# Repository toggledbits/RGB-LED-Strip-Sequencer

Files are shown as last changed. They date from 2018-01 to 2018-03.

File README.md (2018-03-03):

# RGB LED Strip Sequencer using Arduino & Adafruit Trellis #

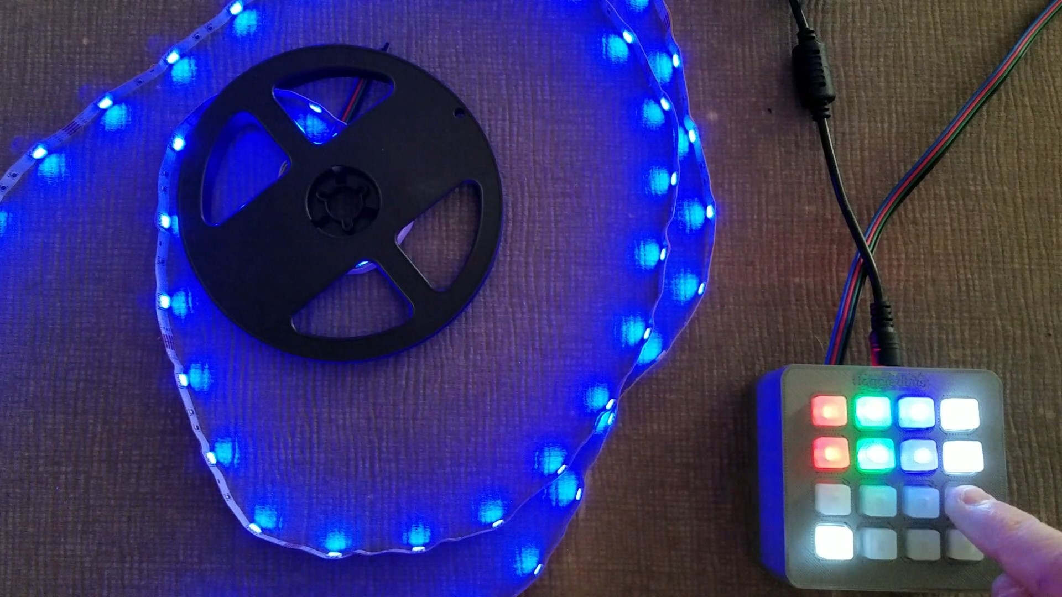
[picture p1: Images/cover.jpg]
toggledbits RGB LED Strip Sequencer (Arduino and Adafruit Trellis)


## Background ##

My wife had been asking me to install LED strips on my boys' hutch-style desks, which were a little dark.
The boys told me they wanted cool color LEDs, not just the white strips that their Mom and I use.
I bought a couple of RGB LED strips on Amazon, most of which seem to come as kits with a power supply 
and controller. But having used the included controllers before, I know that their canned patterns
would quickly become boring to my boys. So, I thought it would better if I built something, using an
Arduino Nano or something similar.

As I thought about the project a little more, I realized that it could be a great opportunity to give them
an intro to programming live projects with a useful result. I've been teaching them programming for a few
months now, but we've mostly been printing to a shell stdout or web page. Here, I had an opportunity to let
them program to blink lights! Any way they want!

So, the project quickly morphed from a 30-minute job getting LED strips to stick to the desk frame to several
weeks of tinkering with Arduino Sketch, circuit design, board layout, and 3D printing. My concept was to build
an Arduino-based LED sequencer that they could use to create simple patterns from a user interface of some kind,
or as their skills grew, implement their patterns within a Sketch that acted like a framework: they just supply
their one part at first, but later they can venture into any part of the code they want.

This repository contains what is currently my version 1.1 effort. 

## What It Does ##

[See it in action on YouTube!](https://youtu.be/xU6wqpSIGhU)

The Arduino drives three MOSFETs to drive the color channels of the LED strip. An [Adafruit Trellis](https://www.adafruit.com/product/1616) 4x4 button 
matrix is used to create the user interface. Color-keying of the button LEDs helps provide visual cues to function
(e.g. changing the red channel intensity is done using the red buttons, green channel using green buttons, etc.).

To turn the project on, long-press the lower-left button. The project lights up all LEDs, then turns off the
bottom two rows except the lower-left (power) button.

The two top rows of buttons change the color intensity of the red, green, and blue channels. Pressing the white
buttons changes the LED strip color to white (all channels driven equally) and varies the intensity in the same
manner as the individual color buttons.

Eight preset patterns are stored in the Arduino's EEPROM. A pattern can be played by pressing one of the eight
buttons in the lower two rows of the pad. The button blinks while the pattern is running. Pressing the button
again stops the pattern. Pressing a different pattern button starts that new pattern. Pressing the intensity
buttons (top two rows) stops the pattern at its current step and changes the color accordingly.

The EEPROM-based patterns can be edited using the keypad interface. A long-press (more than one second) on a
pattern button puts the project into editing mode for that pattern. When in editing mode, the upper two rows
of buttons blink, and the LED strip shows the color of the current step. Pressing the intensity buttons modifies
the color for that step. When a satisfactory color is set, a short press on the pattern button advances to the next step.
These steps are continued until editing completes, either by short press on the 16th step (max 16 steps per pattern), 
or by long-pressing the pattern button at any point. The modified pattern then automatically runs.

To turn the project off, long-press the lower left button.

A "factory reset" of the project, restoring the original default patterns to EEPROM, can be done by pressing
and holding the bottom left and bottom right buttons until the top two LEDs light. Release the buttons, and the
project will restore defaults to EEPROM.

## Operation and Development ##

### Driving the LED Strip ###

The first thing I did was wire up a proto board using MOSFETs to drive the color channels. I used IRLB8721s because
I had a bunch around and they would be fine for handling fairly hefty wattages. The MOSFETs are driven
by the PWM-capable digital outputs on the Ardunio (D9-11, specifically), allowing brightness control.

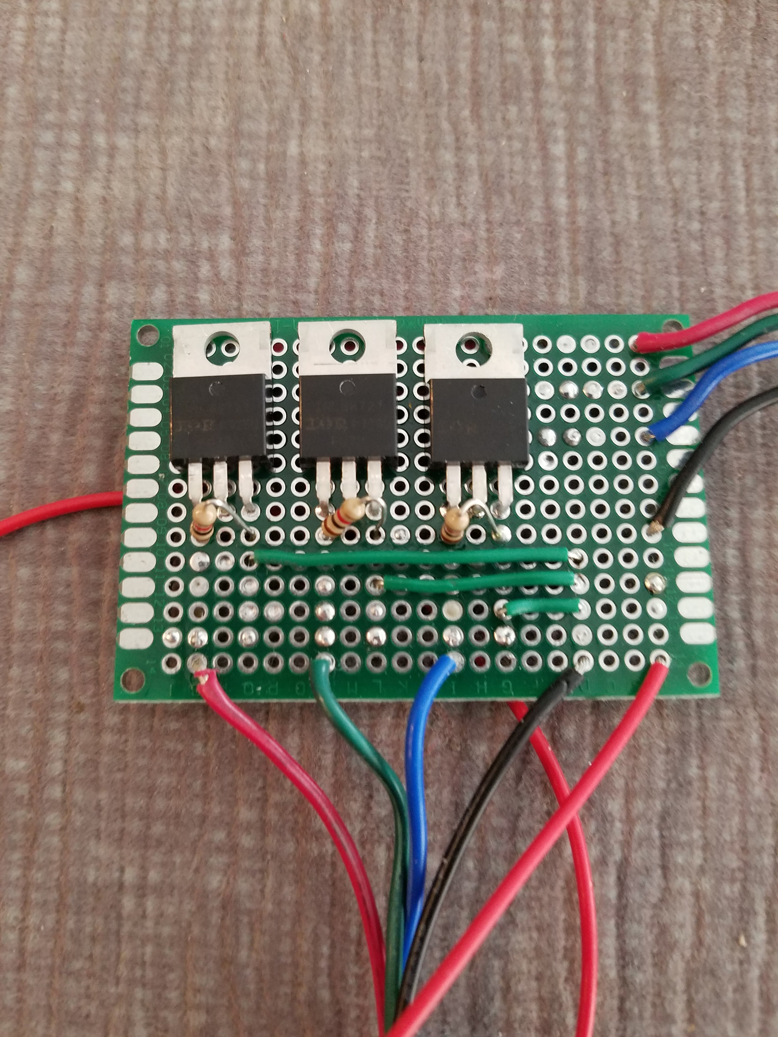
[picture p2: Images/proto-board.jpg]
toggledbits The proto board


### Discovering a User Interface ###

For an interface, I had often used the uniquitous 16x2 LCD with four or five tactile switches for projects, 
but I felt that that kind of interface was going to be slow and clumsy for this purpose. 
What I really thought would work well was a 
matrix of lighted buttons like they use on MIDI controllers. I thought it would be easy to create a simple but
powerful (enough) user interface on it, and the boys would think it was really cool-looking (shout out to Thomas Dolby for
that--it's a long story, maybe ask me over a beer). So I started researching how to build one. Hmmm. That was going
to get expensive. OK, is there an off-the-shelf product that didn't look like a DTMF or calculator keypad
that I could interface with? Few, all expensive.

I don't recall how I found it, but I ended up stumbling across the Adafruit Trellis. It's (as of this writing)
a $9.95 board (plus $4.95 for the silicone keypad--not sure why they sell it separately) with a 4x4 matrix of
addressable switches. The board doesn't come with LEDs, but you can provide your own and solder them to pads
provided. The Arduino library lets you check button states and turn LEDs on and off with simple function calls, and 
the board uses two-wire (I2C) communication. You can even connect up to eight together to make larger matrices.

I ordered one, and started playing with it as soon as it arrived. Perfect. I soon had it working on the Arduino,
and from there, imagining an interface and getting it to work took only a couple of hours.

With the user interface shaping up, I connected everything together, supplied power to the LED strip, and played
with my new toy. This was going to work great for the boys.
Except, I could not imagine putting a spaghetti bundle of three boards and wiring on their desks. That was
fraught with peril. I needed an enclosure, but that wasn't going to be enough.
The solder-globbing style of proto board work left me feeling like it was going to be
a permanently unpolished project. The case my hide the worst of it, but I wanted the project to
look as polished on the inside as it was on outside. The driver board had to be cleaned up.

### Version 1.0 is Born ###

I started designing the driver board as a proper printed circuit board (PCB). It seemed obvious to me to make it a
shield for the Arduino, so the connections between the two could be many and firm. After Googling out a few diagrams,
I had a board properly dimensioned with headers in the right places to be a shield. A quick print at actual size
confirmed the fit. Adding the driver circuit to the board from there was easy, as my driver circuit is simple and even the
small size of the Arduino footprint left plenty of room.

The next consideration was simplifying the power supplies. In the prototype, the LEDs were separately powered, and the
Arduino drew its power from the USB port. It had to work standalone from a single supply. I double-checked the specs for 
the Uno, and 12V supply wasn't going to be a problem. Checking the schematic, I could see there was a VIN header pin that would
give me the supply voltage, but there was a potential problem: the PJ202 jack on the Arduino has a protection diode connected between it and that VIN pin, 
and that diode (and probably the traces on the Arduino) were unlikely to handle the potential power demand that the LED strip
would make on them. The schematic quickly confirmed, however, that I could supply power *to* the Arduino on
the VIN pin, and have the 12V supply connect directly to the shield. This left the matter of getting a 5V supply to the
Trellis, but that's easy because the Arduino supplies 5V from its on-board regulated supply on a header pin. So, in the final result,
12V is supplied to the shield, which sends 12V to the Arduino over VIN, which sends 5V back to the shield, which sends that 5V up to
the Trellis. And, the shield traces are all large enough to handle the larger currents the LED strips require. Done.

Right before I sent the boards out to be fabricated, I realized that I could make holes for stand-offs, so the Trellis could
mount to the shield. This would make a sandwich: Arduino on the bottom, shield connected to it, and Trellis connected to shield
on top. Perfect. I just had to move two traces slightly to get the Trellis mounting holes where they needed to be, and off the v1.0 
board went to the board house.

When I got the boards back, everything went together perfectly. I tested the board standalone, driving it with my bench
power supply, and it seemed to work fine. When I hooked it up to the Arduino, everything worked perfectly. So there it was,
version 1.0.

Check out the [YouTube video](https://youtu.be/SFQtTEeX06Y).

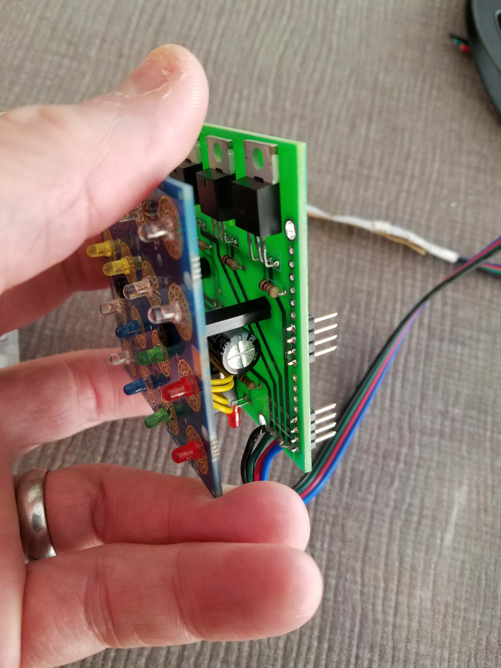
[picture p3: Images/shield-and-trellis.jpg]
toggledbits Trellis on Shield


It took me a few attempts to get the 3D-printed enclosure dialed in. I've only recently started using Fusion 360, and I find it
quite intuitive and easy to work in. I really love it. It's much easier to use and more powerful than my previous go-to tool,
123D Design (also AutoDesk, now discontinued). The lid was actually a snap, because the holes for the Trellis' buttons
are very precisely spaced and Fusion 360 has tools for exactly
that kind of thing. It took me less than 30 minutes to design a lid, and that design changed very little throughout. The body,
however, had holes in two of its vertical sides, and getting those positioned so that they ended up lining up right with my three-board
sandwich took a couple of attempts. Each test print of the body took about 4 hours to print with 200u layers, so it wasn't that it was hard, 
it just took time (shout out to [Josef Prusa and crew](https://www.prusa3d.com/) here--this was my first time using 
my new Prusa i3 MK2S Christmas present on a real project, and it performed beautifully).

The final design looks clean and fits OK. The Arduino is inserted first, on its own, into the bottom of the body. The
shield with the Trellis mounted is then inserted into the Arduino. The lid is then pressed on over the Trellis, and is
held by friction. I could tweak it to death, but I have other ideas about how I want to modify the project that will require
big changes to the enclosure, so it's not worth my time at the moment to sweat over a millimeter here or there.

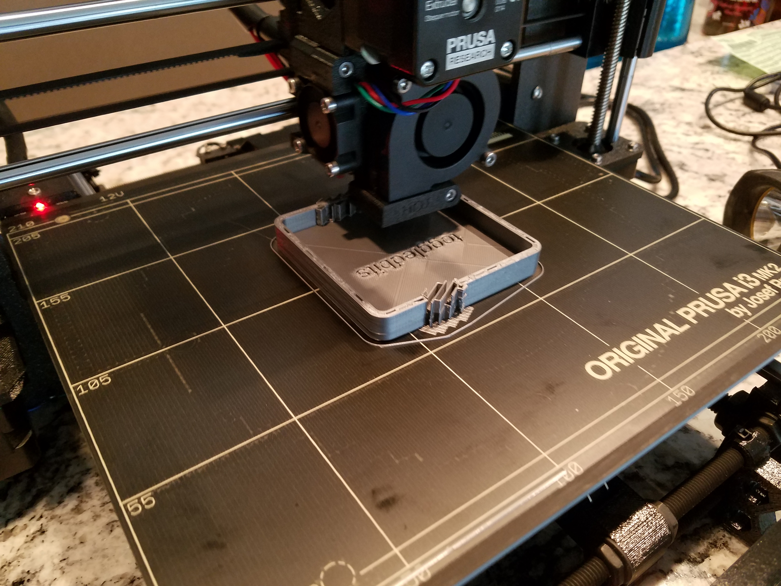
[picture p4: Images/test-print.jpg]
toggledbits An early test print


### Today: Version 1.1 ###

As happens with all prototypes, you discover a few mistakes along the way. In the process of building the first unit for
my older boy, and writing the Instructable to describe the process, I realized that I made two mistakes I would need to
correct right away:

* I needed a protection diode to prevent any power directly into the Arduino from trying to power the LEDs. That is, if
the project was connected to USB for Sketch updating and the 12V supply was not connected, the Arduino would be sending
USB power at 5V up to the shield on the VIN pin, and the shield would attempt to power the LEDs with it. To prevent that,
a diode facing the Arduino has been added to the shield, which blocks any backfeeding of the shield from the Arduino. The
Arduino can be safely connected to USB, and will even power the Trellis, but it won't power the LED circuit on the shield.
* I had forgotten to current limit the digital pins--whoops!--so I added R5-7.
* I had not yet provided a way in the Sketch code to control the rate at which patterns are run. This is now done. In the
run mode, the white up/down keys control the pattern rate. The pattern is stored in EEPROM with the pattern.

So, as it stands today, the project consists of:

1. The custom-designed Arduino shield that creates all of the interfaces for the circuit: input, output, and power;
1. The Arduino Sketch that drives the shield and the Adafruit Trellis;
1. The enclosure designed in Fusion 360 to fit the current hardware configuration.

## What's Next ##

My current thoughts about the next revision of this project are:

1. A version of the driver that accepts a Nano or Feather directly. This will "shorten" the sandwich and make a more compact design.
1. WiFi-enable it so my home automation system can monitor and control it.
1. Modify the case design to that the boards are inserted from the bottom. This will make fitting them into the case easier.
1. I can see how some of the subtle design choices for the enclosure (like wall thickness) dramatically affect print time, so I'll tune the enclosure to make printing quicker and use less material.

## Build One! ##

If you want to build one, check out the [YouTube video](https://youtu.be/SFQtTEeX06Y) and [Instructable](https://www.instructables.com/id/Programmable-RGB-LED-Sequencer-using-Arduino-and-A/) I made about building this project.

This Github repository contains all of the files you need: schematics, board layouts (if you decide to build the shield instead of just
using a proto board or breadboard), the Arduino Sketch, and the enclosure model (STL) files.

The enclosure models (STLs) are also [on Thingiverse](https://www.thingiverse.com/thing:2768560).

## Write Your Own Pattern Runner ##

As of version 1.1 of the code, you have the ability to easily write your own patterns into Sketch, if the pushbutton
user interface doesn't provide you enough flexibility. Here's what you need to know.

Patterns are run by a subclass of `PatternRunner`. Your class must have three methods: `start`, `next`, and `stop`. You
can look at the class `ColorWheelRunner` as an example. The `start` method is used to do whatever is necessary to 
initialize the pattern. It must also set the LED strip to the pattern's first step (see below). The `next` method is
then called repeatedly at the pattern delay interval to put the next pattern on the LED strip. Your subclass must
maintain enough state (e.g. private data) to know what step is next. Finally, when the user wants to stop the pattern,
the `stop` method is called. In most cases, this method really won't need to do anything.

To set the LED strip colors, the subclass methods should set the `red`, `green`, and `blue` global variables to the
desired values (0-255), and then call `setRGBW()`. Yes, the globals are gross and the OO is inconsistent; I'll clean
it up some day, I promise.

To set the default pattern delay interval, your subclass can set the global `nextStepDelay`. This value is in milliseconds,
and must be greater than or equal to zero.

To bind your runner to a button, go to the `setup()` function, and near its end you'll see the code below. The bold line is an example
of how and where you add your pattern runner. In this example, we bind a new runner to pattern 0 (first button the third row).

<pre>
  EEPROMRunner er = EEPROMRunner();
  for ( uint8_t i=0; i<8; ++i) {
    patternRunners[i] = &er;
  }
  /* Provide any overrides for the default pattern function here */
  patternRunners[4] = new ColorWheelRunner(); /* override for button 13/power button/pattern 5 */
  <b>patternRunners[0] = new MyNewPatternRunner();</b>
</pre>

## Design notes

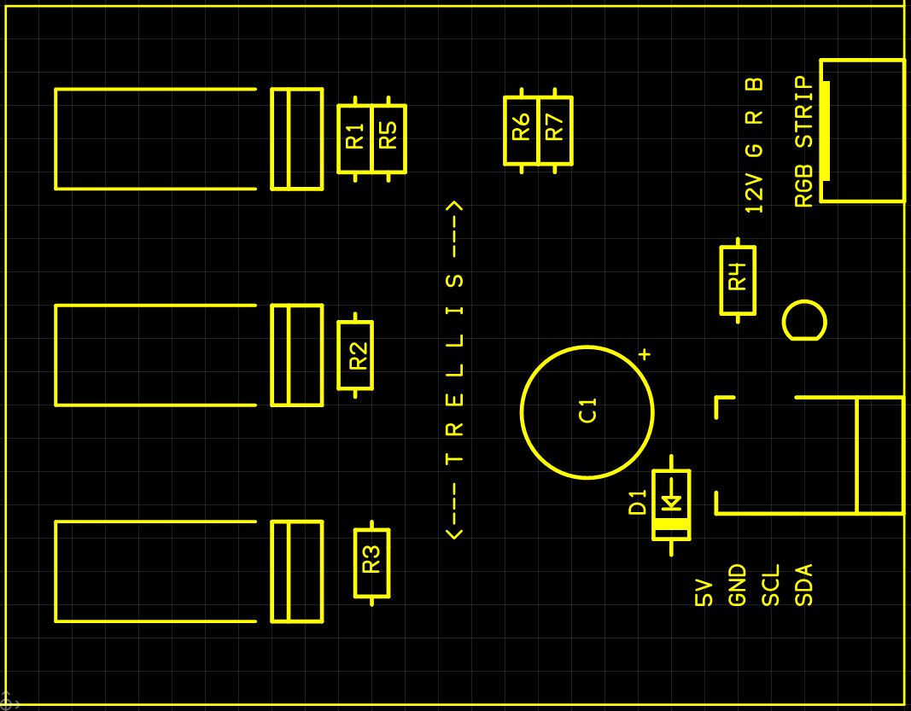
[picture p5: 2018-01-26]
Shield/RGB LED Driver Shield-v1.1-silk.PNG

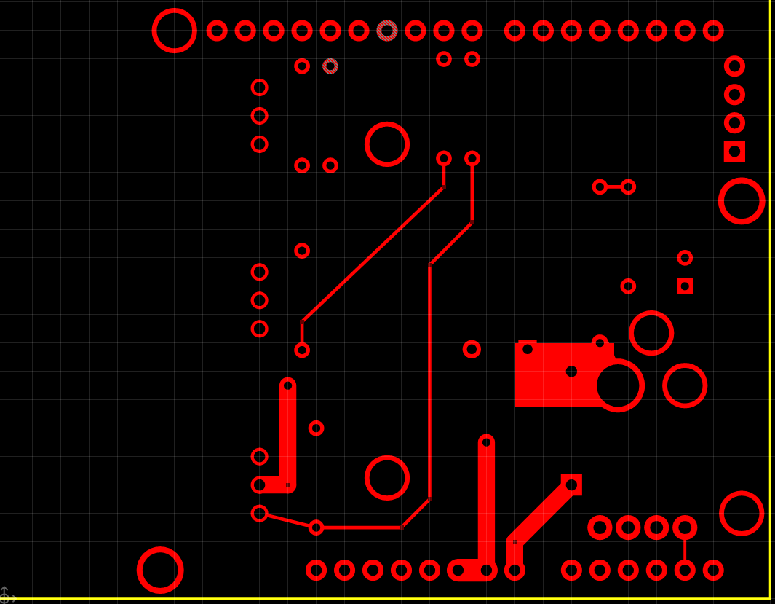
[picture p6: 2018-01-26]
Shield/RGB LED Driver Shield-v1.1-top.PNG

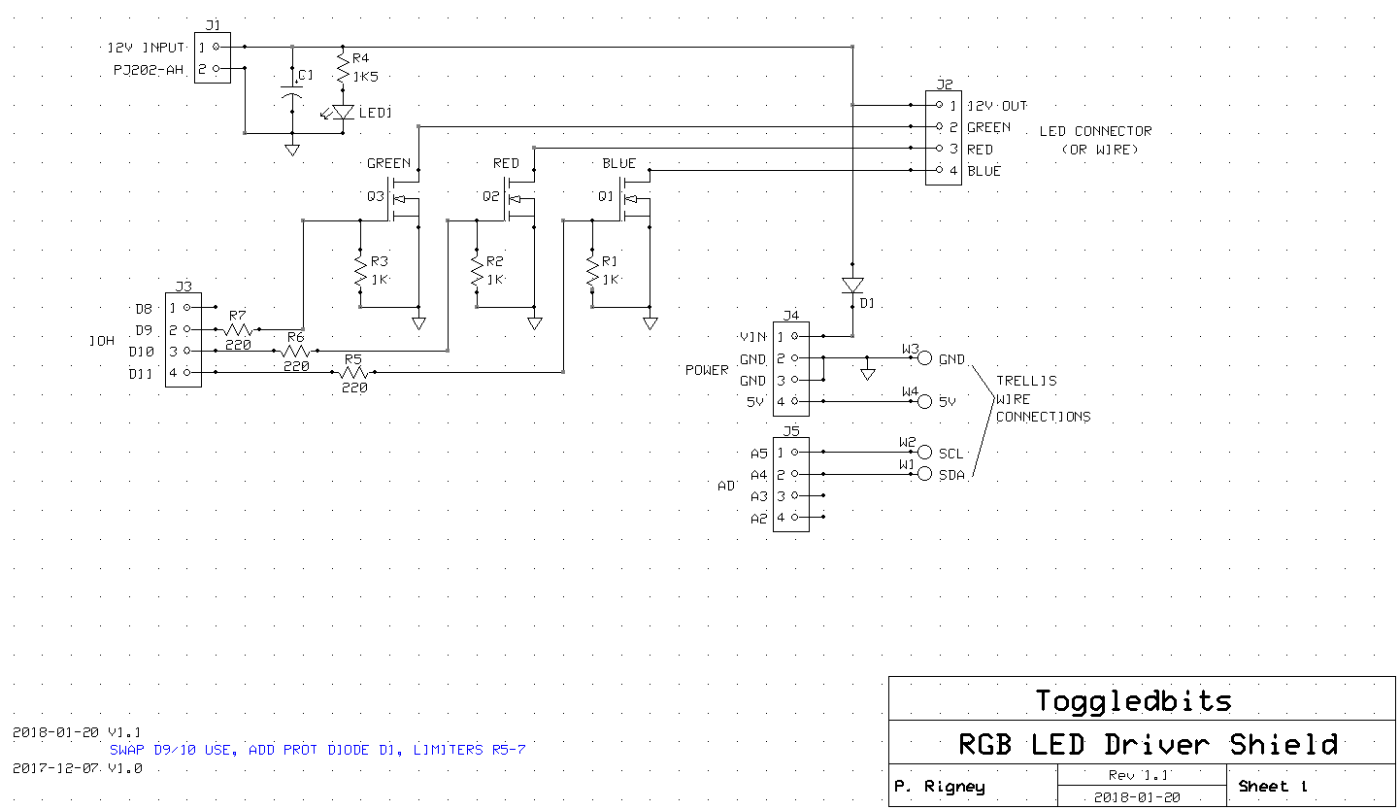
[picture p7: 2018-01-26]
Shield/RGB LED Driver Shield-v1.1-schem.PNG

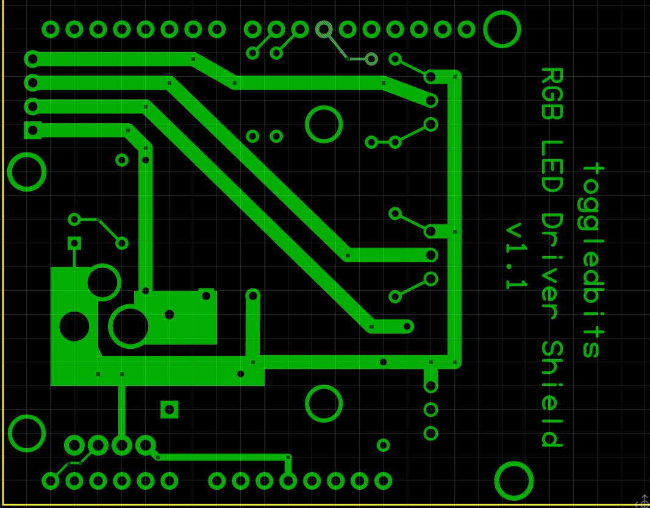
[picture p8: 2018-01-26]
Shield/RGB LED Driver Shield-v1.1-bottom.PNG

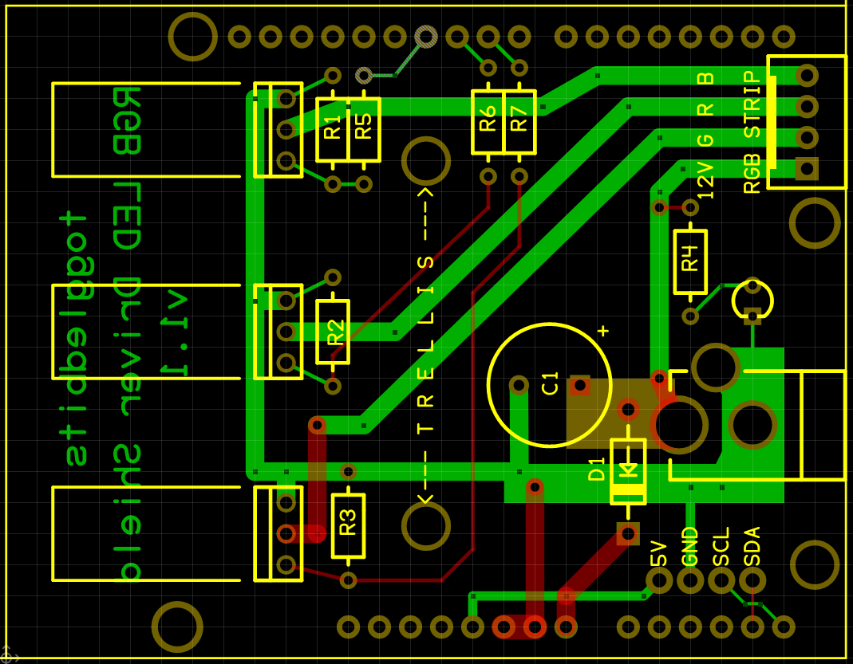
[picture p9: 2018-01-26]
Shield/RGB LED Driver Shield-v1.1-xray.PNG

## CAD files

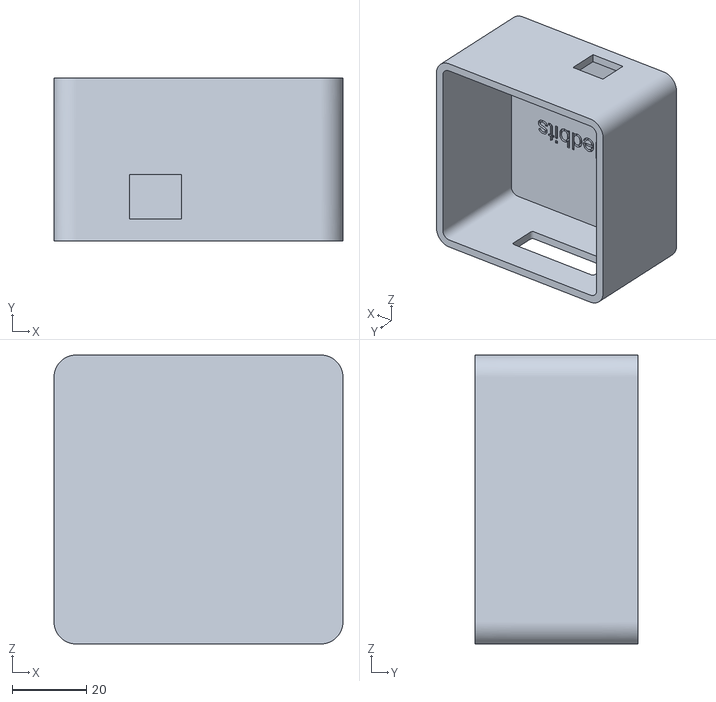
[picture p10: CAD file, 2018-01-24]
Enclosure/Body v27 Final.stl
78.0 x 44.0 x 78.0

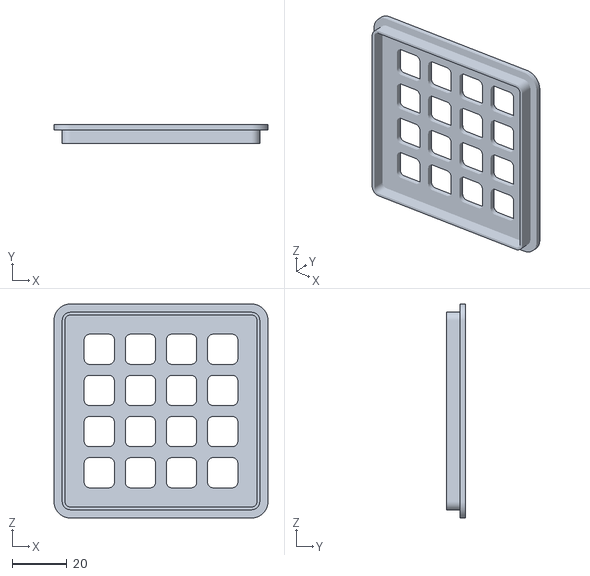
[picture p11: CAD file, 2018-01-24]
Enclosure/Lid v27 Final.stl
78.0 x 7.00 x 78.0

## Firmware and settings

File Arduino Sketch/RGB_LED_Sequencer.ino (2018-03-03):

/*
 * RGB (and optionally W) LED strip sequencer/controller.
 * @author Patrick H. Rigney
 * @version 1.2 2018-03-03
 * 
 * This program controls an RGB LED strip, allowing control of the brightness of
 * each channel, and the playback of eight different sequences of up to 16 steps
 * each. It uses an Adafruit Trellis with LEDs mounted as the user interface. The
 * LED strips are driven by MOSFETs controlled through the use of PWM on digital
 * pins.
 * 
 * I wanted to use LEDs to light my kids' desks. I was going to install plain
 * white strips with a standard dimmer, but they wanted color. But all of the
 * RGB controllers had canned patterns and I knew they would get tired of them
 * (we use such a beast for lighting on our golf cart and few of the patterns
 * are very interesting). It then occurred to me that I could one using a 'duino,
 * and in the process, given them an application where they could eventually take
 * the code and modify it to do more interesting things.
 * 
 * Target: Arduino Uno (Genuino)
 * 
 * Github Repo: https://github.com/toggledbits/RGB-LED-Strip-Sequencer
 * 
 * The circuit:
 * Pin configurations are generally settable by modifying the #defines below, but
 * the system was designed as follows:
 * 
 * A4 and A5 - Connect to Trellis SDA and SCL respectively. 5V and GND
 * are connected as usual. This is the "reference" (example) connection for the
 * Trellis. The INT of the Trellis is not used.
 * 
 * Digital 9, 10, and 11 connect to the MOSFET driver gates.
 * The LED strip leads for each color (cathodes) are connected to the MOSFET drains.
 * The MOSFET sources are connected to ground (N-channel enhancement). The driver
 * MUST be connected in common with the Arduino/5V system ground (same reference).
 * 
 * In my design, I color-coded the Trelis LEDs (loosely) to correspond to button
 * functions. Thus the top two rows of the Trellis (buttons 0-7) are red, green,
 * blue, and white (that sequence on each of the first two rows), as these buttons 
 * are used to raise and lower the LED strip brightness of the color channel cor-
 * responding to the LED color (that is, the red Trellis buttons raise and lower the
 * red LED strip channel brightness). In the current design, my strip does not use
 * white, so I have repurposed these buttons and associated variables to adjust the
 * timing of the LED sequences (faster and slower). Trellis buttons 8, 9, 12, and 13
 * (the lower left quadrant) were given white LEDs, and 10, 11, 14, and 15 (the lower
 * right quadrant) were given yellow LEDs. That was pretty much an arbitrary choice.
 * Their color doesn't really matter, but that choice looks tidy in practice. All one
 * color would also work out well (white recommended).
 * 
 * Use:
 * When the 'duino powers up, it initializes the Trellis library and various globals for
 * its button and sequence processing, and waits in the "OFF" state (no LEDs on). The 
 * Trellis is unlit at this point. Press and hold the lower-left Trellis button to turn
 * the unit ON. The system will power up the Trellis display, lighting the 8 color con-
 * trol buttons (0-7) and the lower-left (12) button (as a power indicator, redundant).
 * The system also checks the EEPROM by computing a checksum for its data. If the
 * checksum and data don't agree, the default pattern array is written to EEPROM.
 * 
 * The system powers to IDLE state. In this state, the color output of the LED drivers
 * can be modified using buttons 0-7 (for example, buttons 0 and 4 raise and lower,
 * respectively, the brightness of the red LED strip channel if everything is connected
 * correctly). To run a pattern, briefly press one of the pattern buttons 8-15 (the
 * lower two rows of buttons). There are eight-preprogrammed sequences or patterns
 * defined. Stop a running pattern by either pressing the same pattern button again
 * (the button of the running pattern is the blinking one, so press the blinking one).
 * Pressing the white up/down buttons during run speed up or slow down the pattern.
 * 
 * Patterns can be edited, and the edited pattern is stored in EEPROM. To edit a pattern,
 * "long-press" (more than one second) any of the pattern buttons except 13 (more below).
 * The pattern button will light solid, and the brightness buttons will blink. Adjust the
 * brightness of each channel to achieve the desired color and brightness for the first
 * step of your pattern, then briefly press the (solid) pattern button again. Each press
 * of the pattern button saves the current brightness as a step and moves to the next.
 * A long press of the pattern button ends editing. Editing also ends when the last 
 * possible step (16 currently) has been saved. The pattern then runs. Ending editing
 * with a long press sets the pattern length to the current step, so be careful when
 * editing an existing pattern--if you make a change to step 3 of an 8-step pattern
 * and then bail out with a long press, the pattern is shortened to 3 steps.
 * 
 * To turn the system off, press and hold button 12 (lower left). Because of this, pre-
 * defined pattern 5 cannot be edited, as the long-press is used for power off in pref-
 * erence to entering edit mode. Maybe a two-button sequence could be implemented instead,
 * but for now, this is good enough.
 * 
 * Long-pressing buttons 13 and 16 together while the system is in the OFF state will
 * cause it to "factory reset" by rewriting the origin pattern set back to EEPROM. We do
 * this by simply mangling the EEPROM checksum, and allowing the next reset to see that
 * it's wrong.
 * 
 * Finally, if a button is not pressed for DIMDELAY ms, the system dims the Trellis to
 * its lowest brightness. A button press restores full brightness.
 * 
 * -------------------------------------------------------------------------------------
 * REVISION HISTORY
 * 
 * 2018-03-03 Revision 1.2
 * Fix a bug with button handling during edit.
 *
 * 2018-01-27 Revision 1.1
 * Add/finalize handling of pattern rate change. The white up/down buttons are now used
 * to set the pattern rate. If the pattern is an EEPROM canned pattern, the last rate
 * used is stored with the pattern and restore when the pattern is later used.
 * Running of patterns is now push to a subclass of PatternRunner. The default class,
 * EEPROMRunner, runs a pattern from the EEPROM store. This allows others to add patterns
 * by making their own subclass of PatternRunner. A ColorWheelRunner pattern is pro-
 * vided to demostrate; it is bound to button 13 by default. See the Github README.md
 * file for more details.
 * 
 */
#include <Adafruit_Trellis.h>
#include <EEPROM.h>

const char PROGMEM copy[] = "(c) 2017 Patrick H. Rigney, All Rights Reserved.";

/* -------- T R E L L I S   C O N F I G U R A T I O N -------- */

Adafruit_Trellis matrix = Adafruit_Trellis();
Adafruit_TrellisSet trellis = Adafruit_TrellisSet(&matrix);
#define numKeys 16

/* -------- L E D   S T R I P   D R I V E R   C O N F I G U R A T I O N -------- */

/* Uno PWM pins are 3, 5, 6, 9, 10, 11 */
#define RGBPIN_RED 10
#define RGBPIN_GREEN 9
#define RGBPIN_BLUE 11

/* 
 * Pre-defined (default) patterns. These are loaded into EEPROM during setup
 * if they have not been previously initialized there. Take care that the total
 * size of the array does not exceed the EEPROM size of the Arduino.
 */
void colorWheel(void);
#define MAXSTEP 16  /* Max steps allowed in pattern. */
typedef struct {
  short len;
  unsigned short dly;
  unsigned long steps[MAXSTEP];
} Pattern;
const Pattern PROGMEM Seqs[] = {
  /* 0 */  { 12, 250, 0x00ff0000, 0x00ff8000, 0x00ffff00, 0x0080ff00, 0x0000ff00, 0x0000ff80, 0x0000ffff, 0x000080ff, 0x000000ff, 0x008000ff, 0x00ff00ff, 0x00ff0080 },
  /* 1 */  { 12, 200, 0x00200000, 0x00400000, 0x00800000, 0x00c00000, 0x00e00000, 0x00ff0000, 0x00e00000, 0x00c00000, 0x00800000, 0x00400000, 0x00200000, 0x00100000 },
  /* 2 */  { 12, 200, 0x00002000, 0x00004000, 0x00008000, 0x0000c000, 0x0000e000, 0x0000ff00, 0x0000e000, 0x0000c000, 0x00008000, 0x00004000, 0x00002000, 0x00001000 },
  /* 3 */  { 12, 200, 0x00000020, 0x00000040, 0x00000080, 0x000000c0, 0x000000e0, 0x000000ff, 0x000000e0, 0x000000c0, 0x00000080, 0x00000040, 0x00000020, 0x00000010 },
  /* 4 */  { 1, 0xffff, 0xFFFFFFFF },
  /* 5 */  { 1, 0xffff, 0x00FF0000 },
  /* 6 */  { 1, 0xffff, 0x0000FF00 },
  /* 7 */  { 1, 0xffff, 0x000000FF },
};
#define NUMSEQ (sizeof Seqs / sizeof(Pattern))

/* Working variables and constants for pattern run */
#define PATTERN_START 0
#define PATTERN_NEXT 1
#define PATTERN_STOP 2
unsigned long nextStepTime;         /* The time (ms) for the next step to run */
short nextStepDelay;                /* Delay (ms) between steps */
const short DelayIncrement = 10;    /* Increment/decrement of delay (white buttons during run) */
const short MaxDelay = 5000;        /* Maximum delay (ms); min is always 0 */
short currentSequence;              /* Current pattern sequence in RAM */

/* Working variables for EEPROM pattern run and edit */
typedef struct {
  Pattern pattern;  /* RAM copy of pattern */
  short nextStep;   /* Next step to run */
} SeqData;
SeqData seqData;
uint8_t editButton;   /* In edit mode, the button that is being edited */

/*  The PatternRunner class defines an abstract for  objects that run each
 *  of the available patterns. By default, seven of the patterns are EEPROM
 *  canned patterns that are run by the EEPROMRunner subclass (defined below).
 *  One pattern is run on the ColorWheelRunner subclass, which is a demo
 *  class to show how to write and connect a pattern runner.
 */
class PatternRunner {
  public:
    virtual void start( int num ){};
    virtual void next( ){};
    virtual void stop( ){};
};
PatternRunner *patternRunners[8];

/* Working variables for RGB drivers */
short red, green, blue, white;        /* Current/new RGB and W values; yes, signed */
const short ColorIncrement = 8;       /* Inc/dec amount for intensity buttons */

/* Some helpful macros for dealing with color */
#define LS(b,n) (((unsigned long)(b & 0xff))<<n)
#define LONGRGB( w, r, g, b ) (LS(w,24)|LS(r,16)|LS(g,8)|(b&0xff))

/* Working variables for system state */
#define STATE_OFF 0
#define STATE_IDLE 1
#define STATE_GETEDITBTN 2
#define STATE_EDITSEQ 3
#define STATE_RUN 4
uint8_t state = STATE_OFF;          /* Current system state */

/* Working variables for button handling */
typedef unsigned short button_t;
#define DIMDELAY 30000
#define NOBUTTON 0x00ff
#define BUTTONMASK 0x00ff
#define LONGPRESS 0x8000
#define SHORTPRESS 0x4000
#define KEYREPEAT 0x2000
#define BUTTON_RED_UP 0
#define BUTTON_GREEN_UP 1
#define BUTTON_BLUE_UP 2
#define BUTTON_WHITE_UP 3
#define BUTTON_RED_DN  4
#define BUTTON_GREEN_DN 5
#define BUTTON_BLUE_DN 6
#define BUTTON_WHITE_DN 7
#define BUTTON_POWER 12
#define BUTTON_RESET 15
unsigned long keyDownTime[numKeys];
unsigned long lastKeyTime;
unsigned long lastButtonCheck;

/* Working variables for LED state tracking. I track them separately from
 * the Trellis' own tracking so I can blink them and restore them individually.
 */
unsigned long ledState = 0;
unsigned long blinkSet = 0;
unsigned long lastBlink = 0;
#define BLINKRATE 250
#define BMASK( button ) (((unsigned short) 1) << (button & BUTTONMASK))

/* Arduino's software reset -- jump to 0 */
void (*resetFunc)(void) = 0;

/*
 * Prototypes to set/enforce argument default.
 */
void mySetLED( uint8_t n, bool state = true, bool update = false );
void myClrLED( uint8_t n, bool update = false );

/*
 * Compute the checksum of the EEPROM storage area as it currently stands.
 * We use NUMSEQ * sizeof(Pattern) + 1 bytes, with the first byte being
 * the stored, previously-computed checksum for comparison.
 * 
 * @returns Checksum for the EEPROM storage area.
 */
uint8_t getEECheck() {
  uint8_t ck = 0;
  short ll = sizeof(Pattern) * NUMSEQ;
  for (uint16_t i=1; i<=ll; ++i) {  
    ck += EEPROM[i] * (i % 16);
  }
  return ck;
}

/* 
 * Put a step of the current (RAM-copy) pattern on the drivers.
 * 
 * @param n The step of the current pattern to be shown.
 */
void showStep() {
  unsigned long rgb = seqData.pattern.steps[ seqData.nextStep ];
  white = (rgb >> 24) & 0xff;
  red = (rgb >> 16) & 0xff;
  green = (rgb >> 8) & 0xff;
  blue = rgb & 0xff;
  // Serial.print("showStep seq "); Serial.print(currentSequence); Serial.print(" step "); Serial.print( p->nextStep ); Serial.print(": ");
  setRGBW();
}

/*
 * Check to see if the next scheduled pattern step is eligible
 * (timing), and display it if so.
 */
void tickSequence( ) {
  if ( currentSequence < 0 ) return; /* assertion */
  /* Is it time for the next step? */
  if ( millis() < nextStepTime )
    return;
  /* Yes, yes it is. */
  patternRunners[ currentSequence ]->next();
  /* Set timing for next */
  nextStepTime = millis() + nextStepDelay;
}

/*
 * Load the specified sequence from EEPROM into RAM.
 * 
 * @param n The number of the sequence to load from EEPROM.
 */
void loadSequence( short n ) {
  uint16_t addr = 1 + n * sizeof(Pattern);
  EEPROM.get( addr, seqData.pattern );
}

class EEPROMRunner : public PatternRunner {
  private:
    int nPattern;
    
  public: 
    void start( int num ) {
      // Serial.print("EEPROMRunner::start"); Serial.println( num, DEC );
      /* Copy pattern from EEPROM to RAM */
      nPattern = num;
      loadSequence( num );
      /* Run the first step */
      seqData.nextStep = 0;
      showStep();
      /* Set timing for next step -- use pattern's setting to start */
      nextStepDelay = seqData.pattern.dly;
      nextStepTime = millis() + nextStepDelay;
    };

    void next() {
      // Serial.print("EEPROMRunner::next "); Serial.println( nPattern, DEC );
      seqData.nextStep += 1;
      if ( seqData.nextStep >= seqData.pattern.len ) {
        seqData.nextStep = 0;
      }
      showStep();
    };
  
    void stop() {
      /* Nothing to do here */
      // Serial.print("EEPROMRunner::stop "); Serial.println( nPattern, DEC );
    };
};

class ColorWheelRunner : public PatternRunner {
  private:
    int state;
    const int inc = 8;

  public:
    void start( int num ) {
      state = 0;
      red = green = blue = 0;
      nextStepDelay = 50;
      setRGBW();
      return NULL;
    }
    void next() {
      switch ( state ) {
        case 0: /* red up */
          red = red + inc;
          if ( red >= 255 ) {
            red = 255;
            ++state;
          }
          break;
        case 1: /* blue down */
          blue = blue - inc;
          if ( blue <= 0 ) {
            blue = 0;
            ++state;
          }
          break;
        case 2: /* green up */
          green = green + inc;
          if ( green >= 255 ) {
            green = 255;
            ++state;
          }
          break;
        case 3: /* red down */
          red = red - inc;
          if ( red <= 0 ) {
            red = 0;
            ++state;
          }
          break;
        case 4: /* blue up */
          blue = blue + inc;
          if ( blue >= 255 ) {
            blue = 255;
            ++state;
          }
          break;
        case 5: /* green down */
          green = green - inc;
          if ( green <= 0 ) {
            green = 0;
            state = 0; /* Start over */
          }
          break;
      }
      setRGBW();
    }
    void stop() {};
};

/*
 * Clear all Trellis LEDs and update display.
 */
void clearLEDs() {
  for (uint8_t i=0; i<numKeys; ++i) {
    trellis.clrLED(i);
    delay(30);
  }
  trellis.writeDisplay();
  ledState = 0;
  delay(30);
}

/*
 * Our own version of (Trellis) setLED, tracks LED state locally.
 * 
 * @param n The number of the LED (button) to set on or off.
 * @param state (optional) state of LED to set (default true = on)
 */
void mySetLED( uint8_t n, bool state, bool update ) {
  if (state) {
    trellis.setLED( n );
    ledState |= (1<<n);
  } else {
    trellis.clrLED( n );
    ledState &= ~(1<<n);
  }
  if ( update ) {
    trellis.writeDisplay();
    delay(30);
  }
}

/*
 * Our own clear tracks LED state locally.
 * 
 * @param n The number of the LED (button) to turn off.
 */
void myClrLED( uint8_t n, bool update ) {
  mySetLED( n, false, update );
}

/*
 * Use our local state to determine LED status. 
 * 
 * @param n The number of the LED for which to return status.
 * @returns The status, true=on, false=off.
 */
bool myIsLED( uint8_t n ) {
  return (ledState & (1<<n)) != 0;
}

/*
 * Add button to set of buttons that are blinked.
 * 
 * @param btn The number of the button to blink.
 */
void addBlinker( uint8_t btn ) {
  blinkSet = blinkSet | ( 1<<(btn & BUTTONMASK) );
}

/*
 * Set blinkers using a bit mask (bit set = blink).
 * 
 * @param mask Bitmask where 1 sets a button to blinking state, 0 means no change.
 */
void setBlinkers( unsigned short mask ) {
  blinkSet |= mask;
}

/*
 * Return blink condition of a button.
 * 
 * @param btn Button number
 * @returns Blink status of the button
 */
bool isBlinker( uint8_t btn ) {
  return ( blinkSet & (1<<btn) ) != 0;
}

/* 
 *  Clear blinkers using a bit mask (1 = stop blinking).
 *  
 *  @param mask Bitmask where 1 clears the blink state of the button, 0 means no change.
 */
void clearBlinkers( unsigned short mask ) {
  uint8_t k = 0;
  for (k=0; k<numKeys; ++k) {
    if ( mask & (1<<k) ) {
      blinkSet = blinkSet & ~(1<<k);
      mySetLED(k, (ledState & (1<<k)) != 0); /* Return LED to current on/off state */
    }
  }
  trellis.writeDisplay();
  delay(30);
}

/*
 * Stop blinking specified button.
 * 
 * Uses the tracked on/off state of the button to restore it
 * to its "natural" state (on or off).
 * 
 * @param btn Button number for which blinking is turned off.
 */
void clearBlinker( uint8_t btn ) {
  blinkSet = blinkSet & ~(1<<btn);
  mySetLED(btn, (ledState & (1<<btn)) != 0, true);
}

/* 
 * Make buttons blink (periodic task).
 */
void updateBlinkers() {
  /* Nothing yet */
  if ( millis() < lastBlink+BLINKRATE ) {
    return;
  }
  for (uint8_t i=0; i<numKeys; ++i) {
    if ( blinkSet & (1<<i) ) {
      if ( trellis.isLED(i) ) {
        trellis.clrLED(i);
      } else {
        trellis.setLED(i);
      }
    }
  }
  lastBlink = millis();
  trellis.writeDisplay();
  delay(30);
}

/*
 * Update LED drivers to current RGBW values.
 */
void setRGBW() {
  // Serial.print("setRGBW R="); Serial.print(red); Serial.print(", G="); Serial.print(green); Serial.print(", B="); Serial.println(blue);
  analogWrite(RGBPIN_RED, red);
  analogWrite(RGBPIN_GREEN, green);
  analogWrite(RGBPIN_BLUE, blue);  
}

/*
 * Increment RGBW parameter, with rounding to step size.
 * 
 * Contrains the result to byte-size values.
 * @param currVal The current value of the parameter.
 * @param incr Increment to apply (positive or negative).
 */
short incrementBrightness( short currVal, short incr ) {
  short aincr = incr < 0 ? -incr : incr;
  currVal = ((currVal + incr) / aincr) * aincr;
  if ( currVal < 0 ) {
    currVal = 0;
  } else if ( currVal > 255 ) {
    currVal = 255;
  }
  return currVal;
}

/*
 * Handle button-based color adjustment.
 * 
 * @param btn Button that's been pressed.
 */
void adjustColor( button_t btn ) {
  switch (btn) {
    case BUTTON_RED_UP:
      red = incrementBrightness( red, ColorIncrement );
      white = 0;
      break;
    case BUTTON_RED_DN:
      red = incrementBrightness( red, -ColorIncrement );
      white = 0;
      break;
    case BUTTON_GREEN_UP:
      green = incrementBrightness( green, ColorIncrement );
      white = 0;
      break;
    case BUTTON_GREEN_DN:
      green = incrementBrightness( green, -ColorIncrement );
      white = 0;
      break;
    case BUTTON_BLUE_UP:
      blue = incrementBrightness( blue, ColorIncrement );
      white = 0;
      break;
    case BUTTON_BLUE_DN:
      blue = incrementBrightness( blue, -ColorIncrement );
      white = 0;
      break;
    case BUTTON_WHITE_UP:
      white = incrementBrightness( white, ColorIncrement );
      red = blue = green = white;
      break;
    case BUTTON_WHITE_DN:
      white = incrementBrightness( white, -ColorIncrement );
      red = blue = green = white;
      break;
  }
  setRGBW();
}

/* 
 * Transition to IDLE state.
 * 
 * @param button The button that was pressed (not used here).
 */
void doIdle( button_t button ) {
  if ( currentSequence >= 0 || state == STATE_RUN ) {
    patternRunners[ currentSequence ]->stop();
  }
  currentSequence = -1;
  state = STATE_IDLE;
  clearBlinkers(0xffff);
}
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
void loop() {
  delay(10);
  
  updateBlinkers();

  /* doNextInSequence? */
  if ( state == STATE_RUN ) {
    tickSequence();  
  }

  if ( lastButtonCheck + 40 > millis() )
    return;
  button_t btn = getButton();
  lastButtonCheck = millis();
  if ( btn == NOBUTTON ) {
    if ( lastKeyTime + DIMDELAY <= millis() ) {
      trellis.setBrightness(1);
    }
    return;
  }
  trellis.setBrightness(15);
  button_t bBit = 1<<(btn & BUTTONMASK);
  button_t bFlags = btn & ~BUTTONMASK;
  
  // Serial.print("State "); Serial.print(state); Serial.print(", button "); Serial.print(btn); Serial.print(" ("); Serial.print(btn,HEX); Serial.println(")");
  // Serial.print("      bBit = "); Serial.print(bBit,HEX); Serial.print(", bFlags = "); Serial.println(bFlags,HEX);
  for (int k=0; k<NTRANS; ++k) {
    if ( Trans[k].currentState == state && Trans[k].button & bBit && Trans[k].flags & bFlags ) {
      // flash( btn, 1, 30 );
      Trans[k].func( btn );
      return;
    }
  }

  /* We didn't figure out what to do... */
  Serial.print(F("*** No action for state ")); Serial.print(state); Serial.print(F(" button ")); Serial.println(btn, HEX);
  flash( btn & BUTTONMASK, 3, 50 );
}

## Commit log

2018-01-24 Initial check-in
    [Body v27 Final.stl, Lid v27 Final.stl, RGB LED Driver Shield-v1.1.sch]
2018-01-25 Clean up around case description, and talk about future plans
2018-01-26 R5-7 Fix
    [RGB LED Driver Shield-v1.1.sch]
2018-03-03 Fix a bug in key handling during pattern edit.
    [RGB_LED_Sequencer.ino]
